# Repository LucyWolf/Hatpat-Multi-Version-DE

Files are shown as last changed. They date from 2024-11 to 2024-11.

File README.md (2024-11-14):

## Hatpat

#Dies ist ein Review
https://github.com/danielfvm/Patstrap

Ein Open-Hardware- und Softwareprojekt, das versucht, haptisches Feedback durch Kopfstreicheln (Head Pat) an den Spieler in VR zu implementieren. Dieses Projekt konzentriert sich hauptsächlich auf die OSC-Unterstützung von VRChat. Das Projekt besteht aus einem Hardwareteil, dem 'Headpat-Strap' oder einfach 'Patstrap', einem Server, der auf dem PC läuft, und den erforderlichen Änderungen an einem VRChat-Avatar, um die Kommunikation über OSC zu unterstützen. Bitte beachte, dass dies nur ein Hobbyprojekt ist, aber fühle dich frei, zu experimentieren, den Code zu bearbeiten oder die Hardware nach deinen Wünschen anzupassen.

>   [!WARNING]
>   Dieses Projekt befindet sich in der Entwicklungsphase. Bitte beachte, dass die Komponenten des Projekts häufigen Änderungen unterliegen.

### Elektronik
Es wurde für einen ESP8266 (WEMOS D1 MINI)
Für das haptische Feedback wurden zwei Vibrating Mini Motoren verwendet, um ein räumliches Feedback am Kopf zu erzeugen.
__________________________________________________
###    Das ist der Bauplan für den ESP D1 Mini.
# Getestet ✓

## Hardware
### Teile
Um dieses Projekt zu realisieren, benötigst du:
- [ESP8266 WEMOS D1 Mini V4.0.0](https://de.aliexpress.com/item/1005006246661815.html) If you use a different ESP, you may need to change the pins in the code.
- 2x [470RΩ Resistors](https://de.aliexpress.com/item/1005001627995396.html)
- 2x [Transistors BC547B](https://de.aliexpress.com/item/1005003450640801.html)
- 2x [Vibrating motors](https://aliexpress.com/item/1005001446097852.html)

Und optional, wenn du einen Akku verwendest:
- 1x [180KΩ Resistors](https://de.aliexpress.com/item/1005001627995396.html)
- 2x [Diodes 1N5817](https://de.aliexpress.com/item/1005002620053985.html)
- [Battery](https://www.amazon.com/dp/B0B7N2T1TD?psc=1&ref=ppx_yo2ov_dt_b_product_details)
- [Battery charger](https://de.aliexpress.com/item/1005006274938832.html)
- [On/Off switch](https://aliexpress.com/item/1005003938856402.html)

### Hier ist der Schaltplan.


### Battery
Für das Laden und die Stromversorgung des Geräts wird ein TP4056 verwendet. Um den Batteriestand zu messen, füge einen 180 kOhm Widerstand an Pin A0 hinzu und aktiviere Battery sense im Skript. Siehe das Schaltbild, um zu erfahren, wie es angeschlossen wird. Dafür werden auch zwei 1N5817-Dioden verwendet, um sicherzustellen, dass das Gerät auch während der Nutzung geladen werden kann.

>    [!WARNING]
>    Das kleine Lademodul wird von den neuen Ladegeräten unterstützt.



# denn server daführ windet ihr unter dem orginal 
https://github.com/danielfvm/Patstrap

____________________________________________________
###    Das ist der Bauplan für den Seeed Xiao ESP32C3.

>   [!WARNING]
>   motoren gehen aber akku monitor nicht

## Hardware
### Teile
Um dieses Projekt zu realisieren, benötigst du:
- [Seeed Studio XIAO ESP32-C3](https://de.aliexpress.com/item/1005006353129383.html) If you use a different ESP, you may need to change the pins in the code.
- 2x [470RΩ Resistors](https://de.aliexpress.com/item/1005001627995396.html)
- 2x [Transistors BC547B](https://de.aliexpress.com/item/1005003450640801.html) 
- 2x [Vibrating motors](https://aliexpress.com/item/1005001446097852.html)

Und optional, wenn du einen Akku verwendest:
- 2x [180KΩ Resistors](https://de.aliexpress.com/item/1005001627995396.html)
- 1x [Diodes 1N5817](https://de.aliexpress.com/item/1005002620053985.html)
- [Battery](https://www.amazon.com/dp/B0B7N2T1TD?psc=1&ref=ppx_yo2ov_dt_b_product_details)
- [On/Off switch](https://aliexpress.com/item/1005003938856402.html)



# denn server daführ windet ihr unter dem orginal 
https://github.com/danielfvm/Patstrap
_________________________________________________________________

### Gehäuse
Das 3D-Modell und die STEP-Datei des Gehäuses, die Platz für die Motor Discs und den ESP8266 (WEMOS D1 MINI) sowie den XIAO ESP32-C3 bieten, sind im Verzeichnis /model verfügbar und können 3D-gedruckt werden. Alternativ kannst du ein normales Kopfband verwenden und die Motor Discs sowie den ESP einfach mit Heißkleber auf einem Kopfband befestigen.

### PCB
Optional kannst du eine Leiterplatte (PCB) für den Patstrap bestellen. Die benötigten Gerber-Dateien für die Bestellung findest du hier. Vielen Dank an The-Prophet für die Erstellung der PCB.

>   [!WARNING]
>   Die PCB wurde bisher noch nicht getestet und befindet sich noch in der Entwicklungsphase!

## Software
### Firmware
Um die Firmware auf den ESP hochzuladen, verwenden wir Visual Studio Code und PlatformIO. Bitte beziehe dich auf die SlimeVR-Dokumentation als Referenz zur Installation der IDE und der Erweiterung. Nach der Installation kannst du dieses Repository herunterladen und den Ordner /firmware in Visual Studio Code öffnen.

Öffne die platformio.ini und ändere die WLAN-Daten:

-DWIFI_CREDS_SSID='"WLAN Name"'
-DWIFI_CREDS_PASSWD='"WLAN Passwort"'
Entferne das ; andere Module ein- oder auszuschalten. 
Die Akkuangabe ist bereits aktiv, wenn du das Skript das erste Mal öffnest,

Ihre Konfigurationsdatei sollte ungefähr so aussehen:
```ini
  -DWIFI_CREDS_SSID='"WLAN Name"'
  -DWIFI_CREDS_PASSWD='"WLAN Passwort"'
  -DPORT=8888  ; Setzt den TCP-Server-Port auf 8888
  ; Uncomment below ONLY if you used a PNP transistor
  ; -DUSE_PNP
  ; Uncomment below if you want to measure battery
  -DUSE_BATTERY
```
Nach Ihren Änderungen können Sie Ihren ESP anschließen, auf "Build" (✓) klicken und es flashen (→). 
Die Schaltflächen finden Sie in Visual Studio Code unten auf der linken Seite.

flash

### Server
Unter "Releases" finden Sie die Binärdateien, um den Server auf Ihrem Computer auszuführen. Der Server fungiert als Mittelsmann, der die Kommunikation zwischen dem Gerät und VRChat ermöglicht. Der Server unterstützt sowohl Windows als auch Linux. Er öffnet ein Fenster, in dem der aktuelle Verbindungsstatus angezeigt wird. Wenn das Flashen der Hardware erfolgreich war und das Gerät läuft, sollten Sie den Text connected sehen. Sie können die Verbindung auch überprüfen, indem Sie die ESP-LED beobachten.

*   Schnelles Blinken (~10 Mal pro Sekunde): Nicht mit WLAN verbunden.
*   Langsame Blinkrate (~1 Mal pro Sekunde): Mit WLAN verbunden, aber nicht mit dem Server verbunden.
*   Dauerhaftes Licht: Verbunden.
*   Kein Licht: Vielleicht nicht eingeschaltet?

#### Port
Du kannst den OSC-Port sowie den Port zum ESP ändern, indem du ein Startargument hinzufügst.

Um den OSC-Port zu ändern, starte den Server über die Eingabeaufforderung und gib patstrap.exe --osc-port 1234 ein. 
Um den ESP-Port zu ändern, gib stattdessen patstrap.exe --esp-port 1234 ein, aber stelle sicher, dass du auch den Port in der platformio.ini-Datei änderst.

Wenn du den Port nicht jedes Mal manuell festlegen möchtest, wenn du den Server startest, kannst du eine .bat-Datei mit folgendem Inhalt erstellen:
```
@echo off
patstrap.exe --osc-port 1234
```
>   [!WICHTIG] 
>   Stelle sicher, dass sich die .bat-Datei im gleichen Ordner wie die .exe-Datei befindet. Alternativ kannst du den vollständigen Pfad zur .exe in der .bat-Datei hinzufügen.

Wenn du [VRCOSC](https://github.com/VolcanicArts/VRCOSC) verwendest, kannst du die .exe zum Autostart hinzufügen und (falls erforderlich) die Startargumente dort hinzufügen.

### VRChat
#### Avatar - Unity
Damit der Patstrap funktioniert, musst du [OSC-Unterstützung in VRChat aktivieren](https://docs.slimevr.dev/server/osc-information.html) und dein Avatar-Modell bearbeiten, um die erforderlichen Collider für die Erkennung von Kopfstreicheleinheiten einzufügen. Dafür benötigst du ein funktionierendes Avatar-Setup in Unity.

Der 470Ω-Widerstand, der an die Basis des BC547B Transistors angeschlossen ist, hat die Aufgabe, den Strom, der zur Basis fließt, zu begrenzen, um den Transistor zu schützen und sicherzustellen, dass er im aktiven Bereich arbeitet.

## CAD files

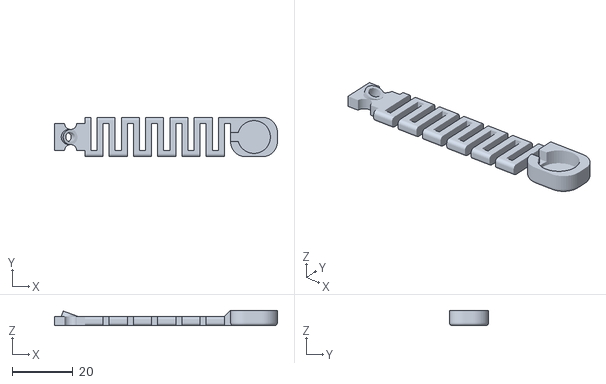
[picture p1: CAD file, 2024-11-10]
STL/Boom Vibrator_Holder V2.stl
73.5 x 13.0 x 5.00

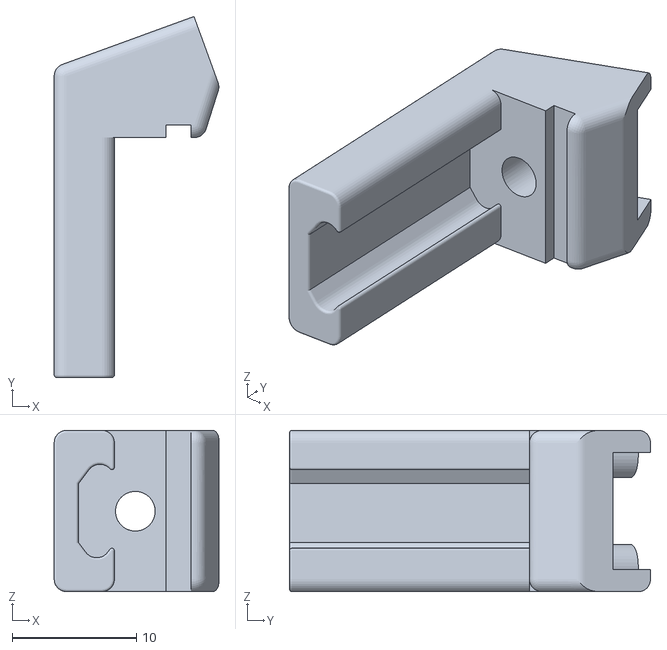
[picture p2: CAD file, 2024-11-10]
STL/Bracket_A_V2.stl
13.3 x 29.1 x 13.0

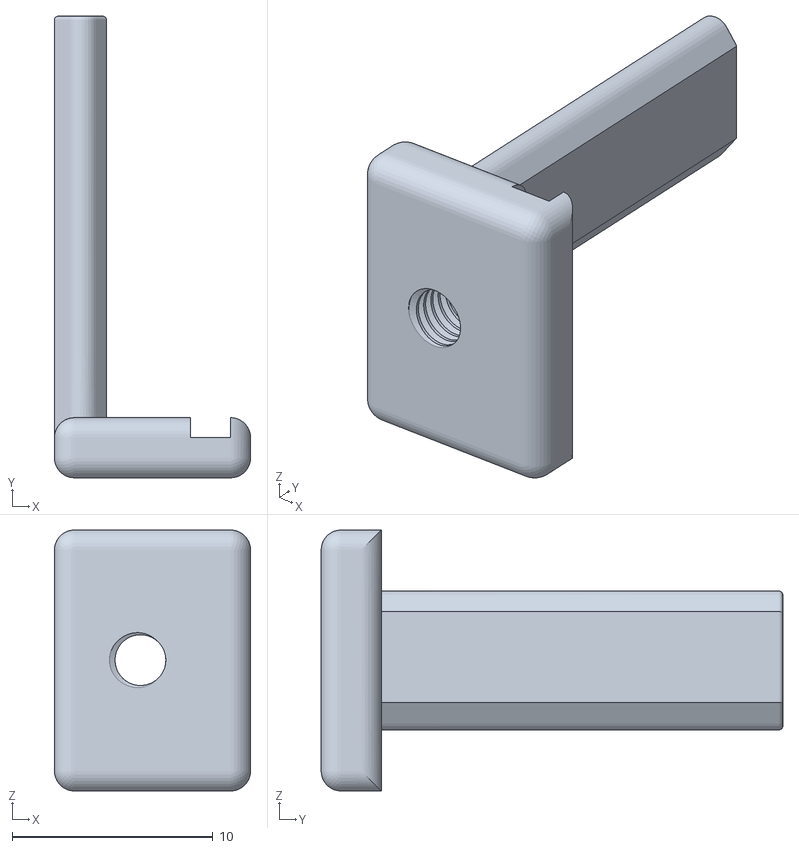
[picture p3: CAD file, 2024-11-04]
STL/Bracket_B_V2.stl
9.77 x 23.0 x 13.0

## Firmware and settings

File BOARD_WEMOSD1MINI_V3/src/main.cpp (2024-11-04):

#include <ESP8266mDNS.h>        // Include the mDNS library
#include <ESP8266WiFi.h>

// Set pin definitions for the WEMOS D1 Mini
#define PIN_BATTERY_LEVEL A0
#define PIN_INTERNAL_LED 2
#define PIN_HAPTIC_LEFT D1
#define PIN_HAPTIC_RIGHT D2

// ADC Configuration
#define ADCResolution 1023.0
#define ADCVoltageMax 1.0

// Server Configuration
#if defined(PORT)
static WiFiServer server(PORT);
#else
#error "Missing -DPORT option in platformio.ini"
#endif

// Haptic Feedback Configuration
#if defined(USE_PNP)
#define HAPTIC_ON LOW
#define HAPTIC_OFF HIGH
#else
#define HAPTIC_ON HIGH
#define HAPTIC_OFF LOW
#endif

// Battery Shield Configuration
#define BATTERY_SHIELD_R1 100.0
#define BATTERY_SHIELD_R2 220.0
#define BATTERY_SHIELD_RESISTANCE 180.0
#define ADCMultiplier ((BATTERY_SHIELD_R1 + BATTERY_SHIELD_R2 + BATTERY_SHIELD_RESISTANCE) / BATTERY_SHIELD_R1)

// Function to get battery level
float getBatteryLevel() {
  float voltage = (analogRead(PIN_BATTERY_LEVEL) * ADCVoltageMax / ADCResolution) * ADCMultiplier;
  float level = 0.0f;

  // Estimate battery level based on voltage ranges
  if (voltage > 3.975f) {
      level = (voltage - 2.920f) * 0.8f;
  } else if (voltage > 3.678f) {
      level = (voltage - 3.300f) * 1.25f;
  } else if (voltage > 3.489f) {
      level = (voltage - 3.400f) * 1.7f;
  } else if (voltage > 3.360f) {
      level = (voltage - 3.300f) * 0.8f;
  } else {
      level = (voltage - 3.200f) * 0.3f;
  }

  // Cut off the last 5% (3.36V) and clamp level between 0 and 1
  level = max(min((level - 0.05f) / 0.95f, 1.0f), 0.0f);
  return level;
}

// Setup function
void setup() {
  // Initialize pins
  pinMode(PIN_INTERNAL_LED, OUTPUT);
  pinMode(PIN_HAPTIC_LEFT, OUTPUT);
  pinMode(PIN_HAPTIC_RIGHT, OUTPUT);
  pinMode(PIN_BATTERY_LEVEL, INPUT);

  // Set initial state of haptic feedback
  digitalWrite(PIN_HAPTIC_LEFT, HAPTIC_OFF);
  digitalWrite(PIN_HAPTIC_RIGHT, HAPTIC_OFF);

  // Initialize serial communication
  Serial.begin(9600);

  // Connect to Wi-Fi
  WiFi.mode(WIFI_STA);
  #if defined(WIFI_CREDS_SSID) && defined(WIFI_CREDS_PASSWD)
    WiFi.begin(WIFI_CREDS_SSID, WIFI_CREDS_PASSWD); // Connect to Wi-Fi
  #else
    #error "Missing -DWIFI_CREDS_SSID and -DWIFI_CREDS_PASSWD options in platformio.ini"
  #endif

  // Wait for Wi-Fi connection
  Serial.println("Connecting to Wi-Fi");
  while (WiFi.status() != WL_CONNECTED) {   
    delay(100);
    digitalWrite(PIN_INTERNAL_LED, LOW);
    Serial.print(".");
    delay(100);
    digitalWrite(PIN_INTERNAL_LED, HIGH);
  }

  // Print IP address and start server
  Serial.print("IP address: ");
  Serial.println(WiFi.localIP());  
  server.begin();

  // Start the mDNS responder for patstrap.local
  if (!MDNS.begin("patstrap")) {
    Serial.println("Error setting up mDNS responder!");
  }
  MDNS.addService("http", "tcp", 80);
  Serial.println("mDNS responder started");

  // Feedback to indicate successful setup
  digitalWrite(PIN_HAPTIC_LEFT, HAPTIC_ON);
  digitalWrite(PIN_HAPTIC_RIGHT, HAPTIC_ON);
  delay(500);
  digitalWrite(PIN_HAPTIC_LEFT, HAPTIC_OFF);
  digitalWrite(PIN_HAPTIC_RIGHT, HAPTIC_OFF);
}

// Main loop
void loop() {
  MDNS.update();

  // Blink internal LED as a heartbeat
  digitalWrite(PIN_INTERNAL_LED, HIGH);
  delay(500);
  digitalWrite(PIN_INTERNAL_LED, LOW);
  delay(500);

  WiFiClient client = server.available();
  
  if (client) {
    Serial.println("Client Connected");

    unsigned long previousMillis = millis();

    while (client.connected()) {
      unsigned long currentMillis = millis();

      // Process received bytes
      while (client.available() > 0) {
        char data = client.read();
        unsigned int haptic_right_level = (data & 0x0F) << 4;
        unsigned int haptic_left_level = data & 0xF0;

        // Complete the haptic level to full range
        haptic_right_level |= haptic_right_level >> 4;
        haptic_left_level |= haptic_left_level >> 4;

        // Generate PWM signal for haptic feedback
        analogWrite(PIN_HAPTIC_LEFT, HAPTIC_OFF ? haptic_left_level : 0xFF - haptic_left_level);
        analogWrite(PIN_HAPTIC_RIGHT, HAPTIC_OFF ? haptic_right_level : 0xFF - haptic_right_level);
      }

      // Send keep-alive packet with averaged battery value
      if (currentMillis - previousMillis >= 1000) {
        // Send keep_alive package every second
        #if defined(USE_BATTERY)
        client.print((char)round(max(min(getBatteryLevel() * 100.0f, 100.0f), 0.0f)));
        #else
        client.print((char)255);  // Indicate no battery information
        #endif

        previousMillis = currentMillis;
        client.flush();
      }
    }

    client.stop();
    Serial.println("Client disconnected");    
  }
}

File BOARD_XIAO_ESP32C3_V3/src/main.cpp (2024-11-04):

// Board-specific configurations
#include <WiFi.h>
#include <ESPmDNS.h>

// Set pin definitions for the XIAO ESP32C3
#define PIN_BATTERY_LEVEL 2 // D0 / A0
#define PIN_HAPTIC_LEFT D1  // Set to D1
#define PIN_HAPTIC_RIGHT D2 // Set to D2
#define PIN_INTERNAL_LED 9 // Set D9 as internal LED pin

// ADC settings for ESP32
#define ADCResolution 4096.0 // 12-bit resolution for ESP32
#define ADCVoltageMax 3.3

// Haptic motor control logic
#if defined(USE_PNP)
#define HAPTIC_ON LOW
#define HAPTIC_OFF HIGH
#else
#define HAPTIC_ON HIGH
#define HAPTIC_OFF LOW
#endif

// Server setup
static WiFiServer server(PORT);

// Battery measurement configuration
#define BATTERY_SHIELD_R1 180.0  // 180 kΩ
#define BATTERY_SHIELD_R2 180.0  // 180 kΩ
#define ADCMultiplier (BATTERY_SHIELD_R1 + BATTERY_SHIELD_R2) / BATTERY_SHIELD_R1 // Multiplier is 2

// Function to get battery voltage
float getBatteryVoltage() {
    uint32_t Vbatt = 0;
    for(int i = 0; i < 16; i++) {
        Vbatt += analogRead(PIN_BATTERY_LEVEL); // ADC reading
    }
    float Vbattf = Vbatt / 16 / 1000.0; // Average and convert to volts
    return Vbattf * ADCMultiplier; // Multiply by ADC multiplier
}

// Function to calculate battery level
float getBatteryLevel() {
    float voltage = ((float)analogRead(PIN_BATTERY_LEVEL)) * ADCVoltageMax / ADCResolution * ADCMultiplier;
    float level = 0.0f;

    if (voltage > 3.975f)
        level = (voltage - 2.920f) * 0.8f;
    else if (voltage > 3.678f)
        level = (voltage - 3.300f) * 1.25f;
    else if (voltage > 3.489f)
        level = (voltage - 3.400f) * 1.7f;
    else if (voltage > 3.360f)
        level = (voltage - 3.300f) * 0.8f;
    else
        level = (voltage - 3.200f) * 0.3f;

    level = (level - 0.05f) / 0.95f;
    level = max(min(level, 1.0f), 0.0f);

    return level;
}

// Function to test the motors
void testMotors() {
    Serial.println("Testing both motors...");
    ledcWrite(0, 255);  // Full power to left motor
    ledcWrite(1, 255);  // Full power to right motor
    delay(1000);        // 1 second
    ledcWrite(0, 0);    // Turn off left motor
    ledcWrite(1, 0);    // Turn off right motor
    Serial.println("Motor test complete.");
}

// Setup function
void setup() {
    pinMode(PIN_INTERNAL_LED, OUTPUT);
    digitalWrite(PIN_INTERNAL_LED, LOW);

    pinMode(PIN_HAPTIC_LEFT, OUTPUT);
    pinMode(PIN_HAPTIC_RIGHT, OUTPUT);
    pinMode(PIN_BATTERY_LEVEL, INPUT);

    Serial.begin(115200);

    WiFi.mode(WIFI_STA);
    WiFi.begin(WIFI_CREDS_SSID, WIFI_CREDS_PASSWD);

    Serial.println("Connecting to Wi-Fi");
    while (WiFi.status() != WL_CONNECTED) {
        delay(100);
        digitalWrite(PIN_INTERNAL_LED, !digitalRead(PIN_INTERNAL_LED));
    }

    Serial.print("IP address: ");
    Serial.println(WiFi.localIP());
    server.begin();

    if (!MDNS.begin("patstrap")) {
        Serial.println("Error setting up MDNS responder!");
    }
    MDNS.addService("http", "tcp", 80);
    Serial.println("mDNS responder started");

    // Setup PWM for motor control
    ledcSetup(0, 5000, 8);
    ledcAttachPin(PIN_HAPTIC_LEFT, 0);
    ledcSetup(1, 5000, 8);
    ledcAttachPin(PIN_HAPTIC_RIGHT, 1);

    testMotors();
}

// Main loop
void loop() {
    delay(500);
    digitalWrite(PIN_INTERNAL_LED, HIGH);
    delay(500);
    digitalWrite(PIN_INTERNAL_LED, LOW);

    // Battery Level Reporting
    Serial.print("Battery Voltage: ");
    Serial.print(getBatteryVoltage());
    Serial.print(" V, Battery Level: ");
    Serial.print(getBatteryLevel() * 100);
    Serial.println(" %");

    WiFiClient client = server.available();
    if (client) {
        Serial.println("Client Connected");
        unsigned long previousMillis = millis();

        while (client.connected()) {
            while (client.available() > 0) {
                char data = client.read();
                unsigned int haptic_right_level = (data & 0x0F) << 4;
                unsigned int haptic_left_level = data & 0xF0;

                Serial.print("Haptic Left Level: ");
                Serial.println(haptic_left_level);
                Serial.print("Haptic Right Level: ");
                Serial.println(haptic_right_level);

                haptic_right_level |= haptic_right_level >> 4;
                haptic_left_level |= haptic_left_level >> 4;

                analogWrite(PIN_HAPTIC_LEFT, HAPTIC_OFF ? haptic_left_level : 0xFF - haptic_left_level);
                analogWrite(PIN_HAPTIC_RIGHT, HAPTIC_OFF ? haptic_right_level : 0xFF - haptic_right_level);
            }

            if (millis() - previousMillis >= 1000) {
                client.print((char)round(max(min(getBatteryLevel() * 100.0f, 100.0f), 0.0f)));
                previousMillis = millis();
                client.flush();
            }
        }

        client.stop();
        Serial.println("Client disconnected");
    }
}
